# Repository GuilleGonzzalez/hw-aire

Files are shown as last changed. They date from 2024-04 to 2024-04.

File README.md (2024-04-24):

# Aire

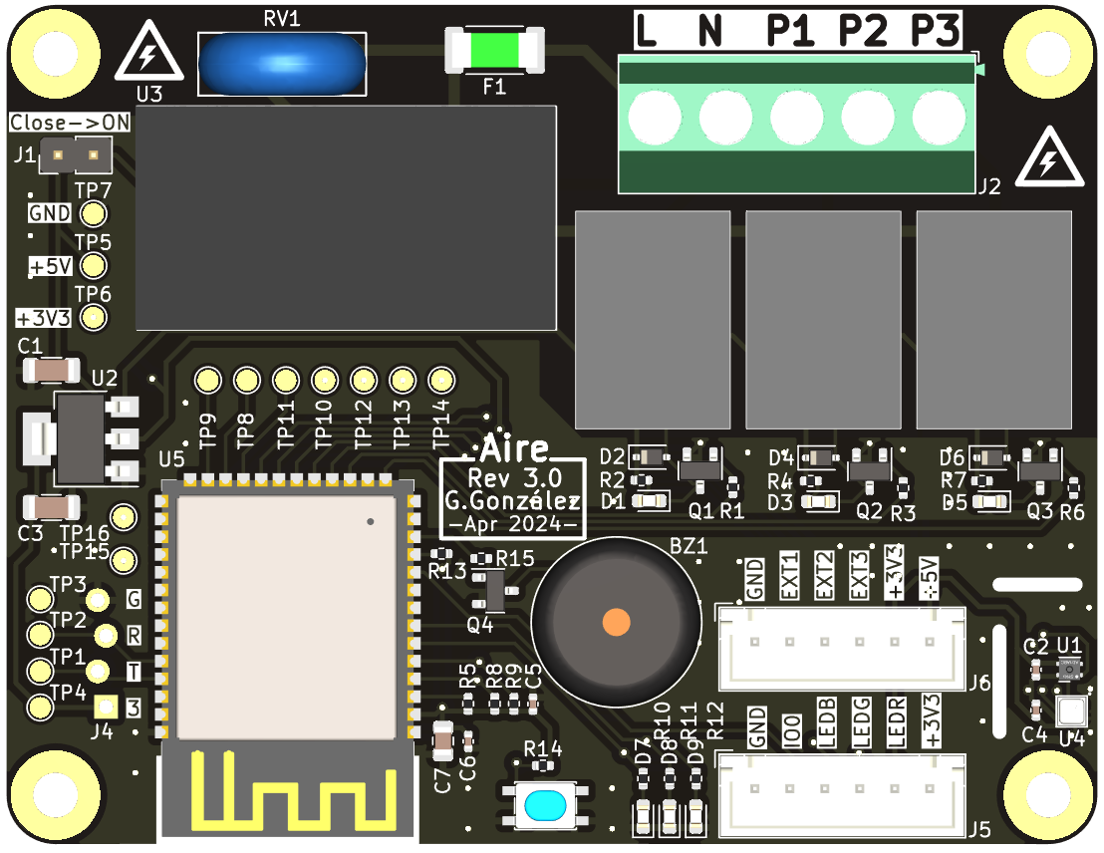
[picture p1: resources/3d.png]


## Description

'Aire' is a PCB designed to control a fan with three relays and automatize it with [Home Assistant](https://www.home-assistant.io/).

Firmware used in this device is [fw-aire](https://github.com/GuilleGonzzalez/fw-aire), a custom made firmware implemented using [Arduino Home Assistant](https://github.com/dawidchyrzynski/arduino-home-assistant/tree/main) Arduino library ([docs](https://dawidchyrzynski.github.io/arduino-home-assistant/)).

## Power supply

The board is powered with a 230VAC power supply.

## Microprocessor

Espressif [ESP32-S2-SOLO](https://www.espressif.com/en/products/modules) module (NRND).

## Environmental sensing

The board has enviromental sensors to measure temperature, humidity and atmospheric pressure:

### Temperature and humidity sensor

* Sensirion [SHT40](https://sensirion.com/products/catalog/SHT40).

### Pressure sensor

* Bosch [BMP581](https://www.bosch-sensortec.com/products/environmental-sensors/pressure-sensors/bmp581/).

## LEDs and buttons

//TODO: review

The device has three LEDs for showing the status to the user.
* A power LED (LED1): shows the status of the fan.
* A general device LED (LED2): shows the status of the general air machine.
* A LED reserved for the future.

The device has a button for flash the firmware in the microcontroller, and is also used for the user.

The board has an external connector available for the three LEDs and the button.

## Pin assignment

| PIN | Func |
| --- | --- |
| TODO | TODO |

## Enclosure (WIP)
* Custom made in [Fusion 360](https://www.autodesk.es/products/fusion-360/overview).

# Changelog
All notable changes to this project will be documented in this section.

The format is based on [Keep a Changelog](https://keepachangelog.com/en/1.0.0/)

## [3.0.0] - 2024-04-24
### Fix
- Change microcontroller for more GPIOs
- Remove IO expander
- SMD LEDs
- Change connectors to JST
- Add external connector
- Envirometal sensors with cutouts for avoid hot
## [2.0.0] - 2023-09-04
### Added
- First stable release in this repository

[Unreleased]: https://github.com/GuilleGonzzalez/hw-aire
[2.0.0]: https://github.com/GuilleGonzzalez/hw-aire/releases/tag/v2.0.0
[3.0.0]: https://github.com/GuilleGonzzalez/hw-aire/releases/tag/v3.0.0

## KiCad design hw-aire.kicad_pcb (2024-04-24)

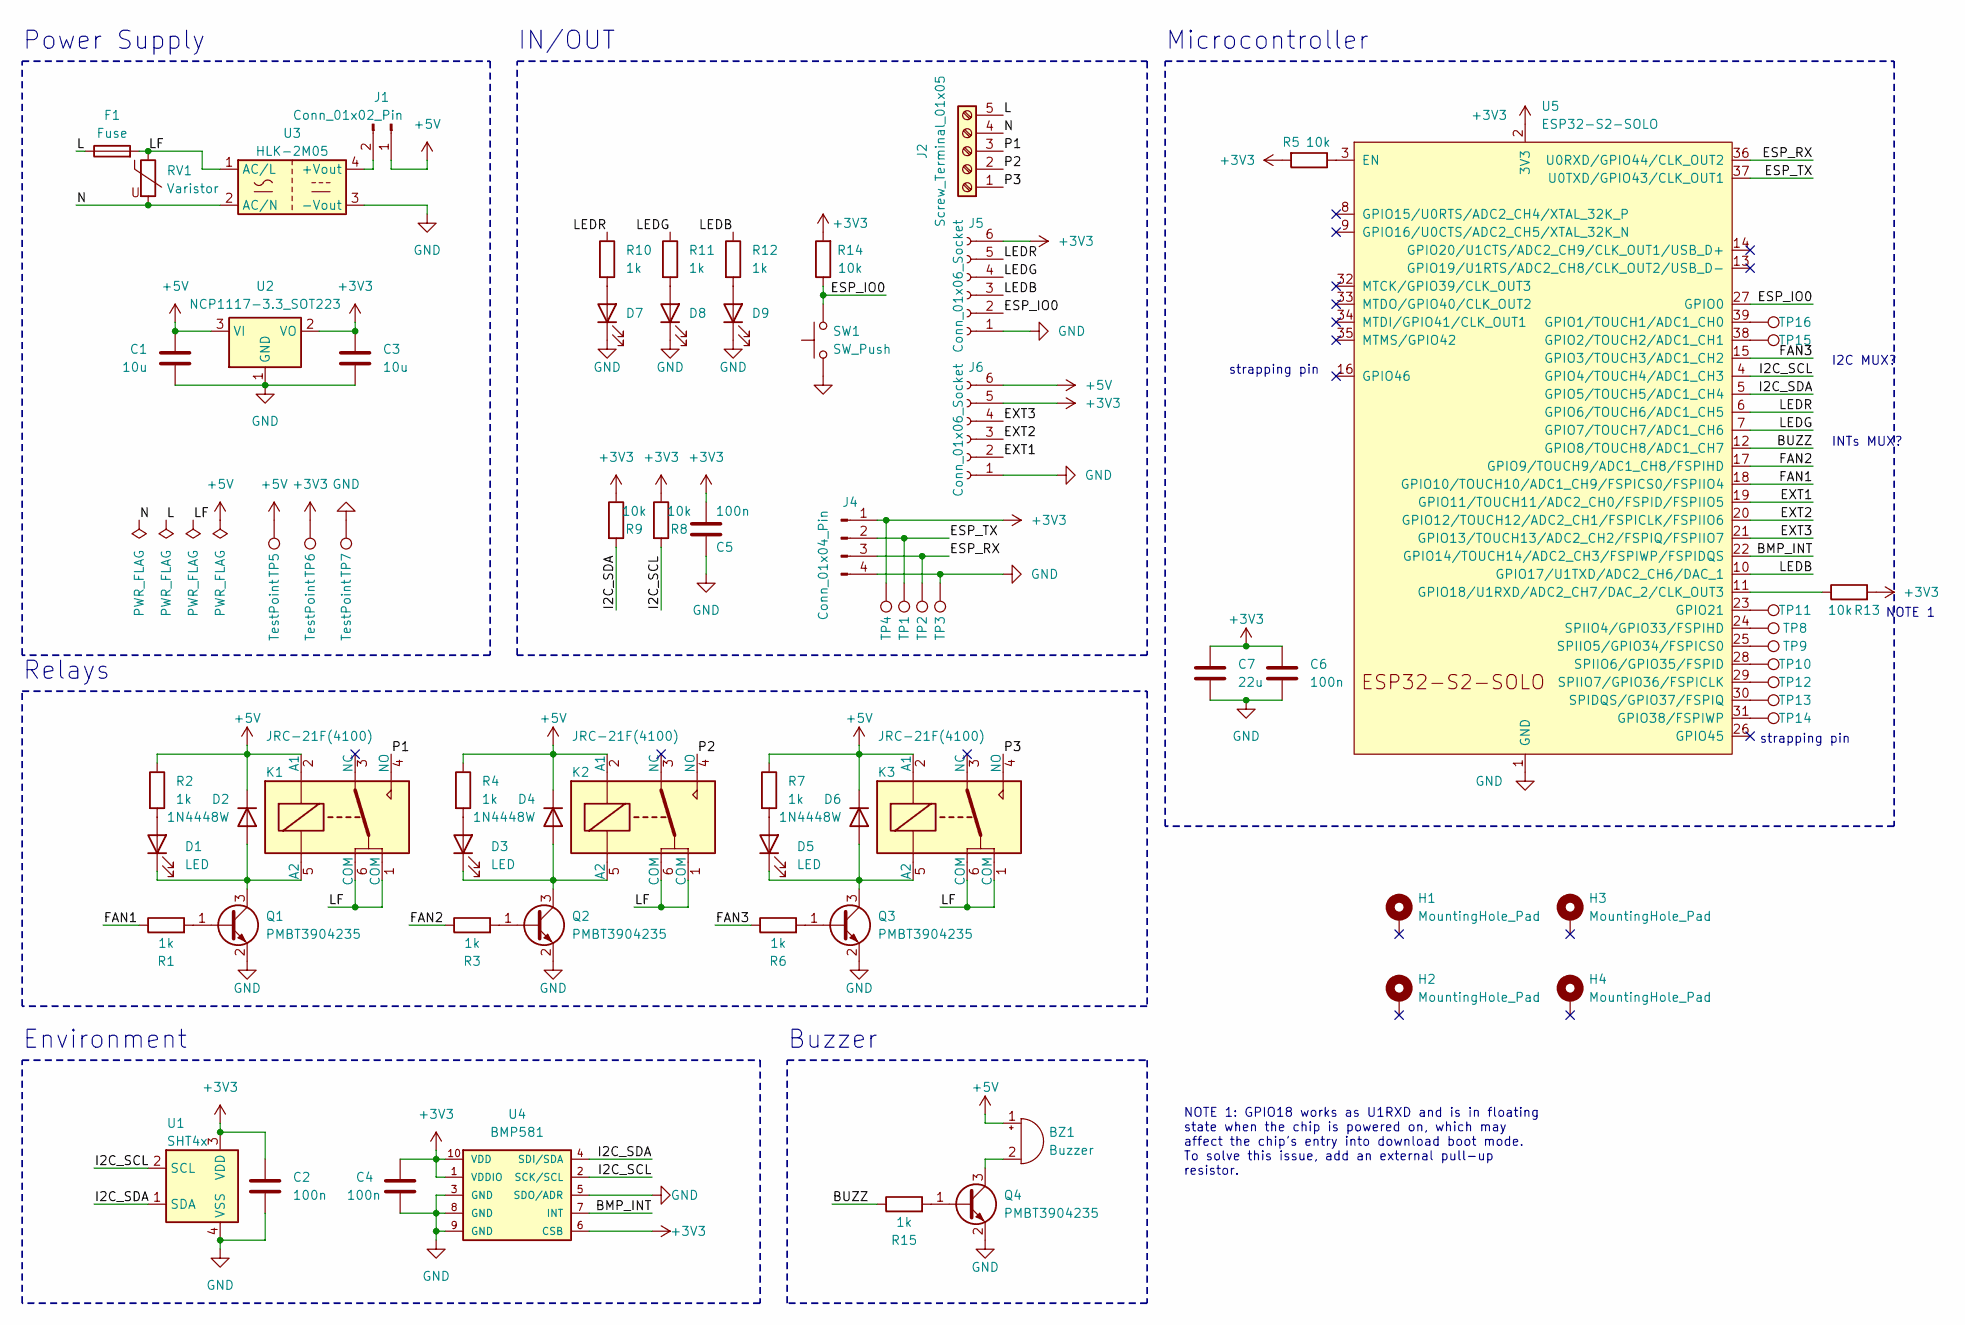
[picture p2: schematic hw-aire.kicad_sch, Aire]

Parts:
BZ1: Buzzer; Buzzer_12x9.5RM7.6
C1, C3: 10u; C_1206_3216Metric
C2, C4, C5, C6: 100n; C_0402_1005Metric
C7: 22u; C_0805_2012Metric
D1, D3, D5, D7, D8, D9: LED; LED_0603_1608Metric
D2, D4, D6: 1N4448W; D_SOD-323
F1: Fuse; Fuse_2512_6332Metric
H1, H2, H3, H4: MountingHole_Pad; MountingHole_3.2mm_M3_Pad_TopBottom
J1: Conn_01x02_Pin; PinHeader_1x02_P2.54mm_Vertical
J2: Screw_Terminal_01x05; TerminalBlock_Phoenix_MKDS-1,5-5-5.08_1x05_P5.08mm_Horizont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
J4: Conn_01x04_Pin; PinHeaderOffset_1x04_P2.54mm_Vertical
J5, J6: Conn_01x06_Socket; JST_XH_B6B-XH-A_1x06_P2.50mm_Vertical
K1, K2, K3: JRC-21F(4100)
Q1, Q2, Q3, Q4: PMBT3904235; SOT-23; Manufacturer_PN PMBT3904,235
R1, R2, R3, R4, R6, R7, R10, R11, R12, R15: 1k; R_0402_1005Metric
R5, R8, R9, R13, R14: 10k; R_0402_1005Metric
RV1: Varistor; RV_Disc_D12mm_W4.5mm_P7.5mm
SW1: SW_Push; SW_SPST_PTS810
TP1, TP2, TP3, TP4, TP5, TP6, TP7, TP8, TP9, TP10, TP11, TP12, TP13, TP14, TP15, TP16: TestPoint; TestPoint_Pad_D1.5mm
U1: SHT4x
U2: NCP1117-3.3_SOT223; SOT-223-3_TabPin2
U3: HLK-2M05
U4: BMP581; Manufacturer PN BMP581
U5: ESP32-S2-SOLO

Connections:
+3V3: C2.1, C3.1, C4.1, C5.1, C6.1, C7.1, J4.1, J5.6, J6.5, R5.2, R8.1, R9.1, R13.2, R14.2, TP4.1, TP6.1, U1.3 (VDD), U2.2 (VO), U4.1 (VDDIO), U4.6 (CSB), U4.10 (VDD), U5.2 (3V3)
+5V: BZ1.1 (-), C1.1, D2.1 (K), D4.1 (K), D6.1 (K), J1.1, J6.6, K1.2 (A1), K2.2 (A1), K3.2 (A1), R2.1, R4.1, R7.1, TP5.1, U2.3 (VI)
/BMP_INT: U4.7 (INT), U5.22 (GPIO14/TOUCH14/ADC2_CH3/FSPIWP/FSPIDQS)
/BUZZ: R15.1, U5.12 (GPIO8/TOUCH8/ADC1_CH7)
/ESP_IO0: J5.2, R14.1, SW1.2, U5.27 (GPIO0)
/ESP_RX: J4.3, TP2.1, U5.36 (U0RXD/GPIO44/CLK_OUT2)
/ESP_TX: J4.2, TP1.1, U5.37 (U0TXD/GPIO43/CLK_OUT1)
/EXT1: J6.2, U5.19 (GPIO11/TOUCH11/ADC2_CH0/FSPID/FSPIIO5)
/EXT2: J6.3, U5.20 (GPIO12/TOUCH12/ADC2_CH1/FSPICLK/FSPIIO6)
/EXT3: J6.4, U5.21 (GPIO13/TOUCH13/ADC2_CH2/FSPIQ/FSPIIO7)
/FAN1: R1.1, U5.18 (GPIO10/TOUCH10/ADC1_CH9/FSPICS0/FSPIIO4)
/FAN2: R3.1, U5.17 (GPIO9/TOUCH9/ADC1_CH8/FSPIHD)
/FAN3: R6.1, U5.15 (GPIO3/TOUCH3/ADC1_CH2)
/I2C_SCL: R8.2, U1.2 (SCL), U4.2 (SCK/SCL), U5.4 (GPIO4/TOUCH4/ADC1_CH3)
/I2C_SDA: R9.2, U1.1 (SDA), U4.4 (SDI/SDA), U5.5 (GPIO5/TOUCH5/ADC1_CH4)
/L: F1.1, J2.5
/LEDB: J5.3, R12.1, U5.10 (GPIO17/U1TXD/ADC2_CH6/DAC_1)
/LEDG: J5.4, R11.1, U5.7 (GPIO7/TOUCH7/ADC1_CH6)
/LEDR: J5.5, R10.1, U5.6 (GPIO6/TOUCH6/ADC1_CH5)
/LF: F1.2, K1.1 (COM), K1.6 (COM), K2.1 (COM), K2.6 (COM), K3.1 (COM), K3.6 (COM), RV1.1, U3.1 (AC/L)
/N: J2.4, RV1.2, U3.2 (AC/N)
/P1: J2.3, K1.4 (NO)
/P2: J2.2, K2.4 (NO)
/P3: J2.1, K3.4 (NO)
GND: C1.2, C2.2, C3.2, C4.2, C5.2, C6.2, C7.2, D7.1 (K), D8.1 (K), D9.1 (K), J4.4, J5.1, J6.1, Q1.2, Q2.2, Q3.2, Q4.2, SW1.1, TP3.1, TP7.1, U1.4 (VSS), U2.1 (GND), U3.3 (-Vout), U4.3 (GND), U4.5 (SDO/ADR), U4.8 (GND), U4.9 (GND), U5.1 (GND), U5.40 (GND), U5.41 (GND)
unnamed: BZ1.2 (+), Q4.3
unnamed: D1.2 (A), R2.2
unnamed: D1.1 (K), D2.2 (A), K1.5 (A2), Q1.3
unnamed: D3.2 (A), R4.2
unnamed: D3.1 (K), D4.2 (A), K2.5 (A2), Q2.3
unnamed: D5.2 (A), R7.2
unnamed: D5.1 (K), D6.2 (A), K3.5 (A2), Q3.3
unnamed: D7.2 (A), R10.2
unnamed: D8.2 (A), R11.2
unnamed: D9.2 (A), R12.2
unnamed: J1.2, U3.4 (+Vout)
unnamed: Q1.1, R1.2
unnamed: Q2.1, R3.2
unnamed: Q3.1, R6.2
unnamed: Q4.1, R15.2
unnamed: R5.1, U5.3 (EN)
unnamed: TP16.1, U5.39 (GPIO1/TOUCH1/ADC1_CH0)
unnamed: TP15.1, U5.38 (GPIO2/TOUCH2/ADC1_CH1)
unnamed: R13.1, U5.11 (GPIO18/U1RXD/ADC2_CH7/DAC_2/CLK_OUT3)
unnamed: TP11.1, U5.23 (GPIO21)
unnamed: TP14.1, U5.31 (GPIO38/FSPIWP)
unnamed: TP13.1, U5.30 (SPIDQS/GPIO37/FSPIQ)
unnamed: TP8.1, U5.24 (SPIIO4/GPIO33/FSPIHD)
unnamed: TP9.1, U5.25 (SPIIO5/GPIO34/FSPICS0)
unnamed: TP10.1, U5.28 (SPIIO6/GPIO35/FSPID)
unnamed: TP12.1, U5.29 (SPIIO7/GPIO36/FSPICLK)

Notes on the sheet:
Buzzer
strapping pin
INTs MUX?
Relays
Power Supply
NOTE 1: GPIO18 works as U1RXD and is in floating state when the chip is powered on, which may affect the chip’s entry into download boot mode. To solve this issue, add an external pull-up resistor.
Environment
NOTE 1
I2C MUX?
Microcontroller
IN/OUT

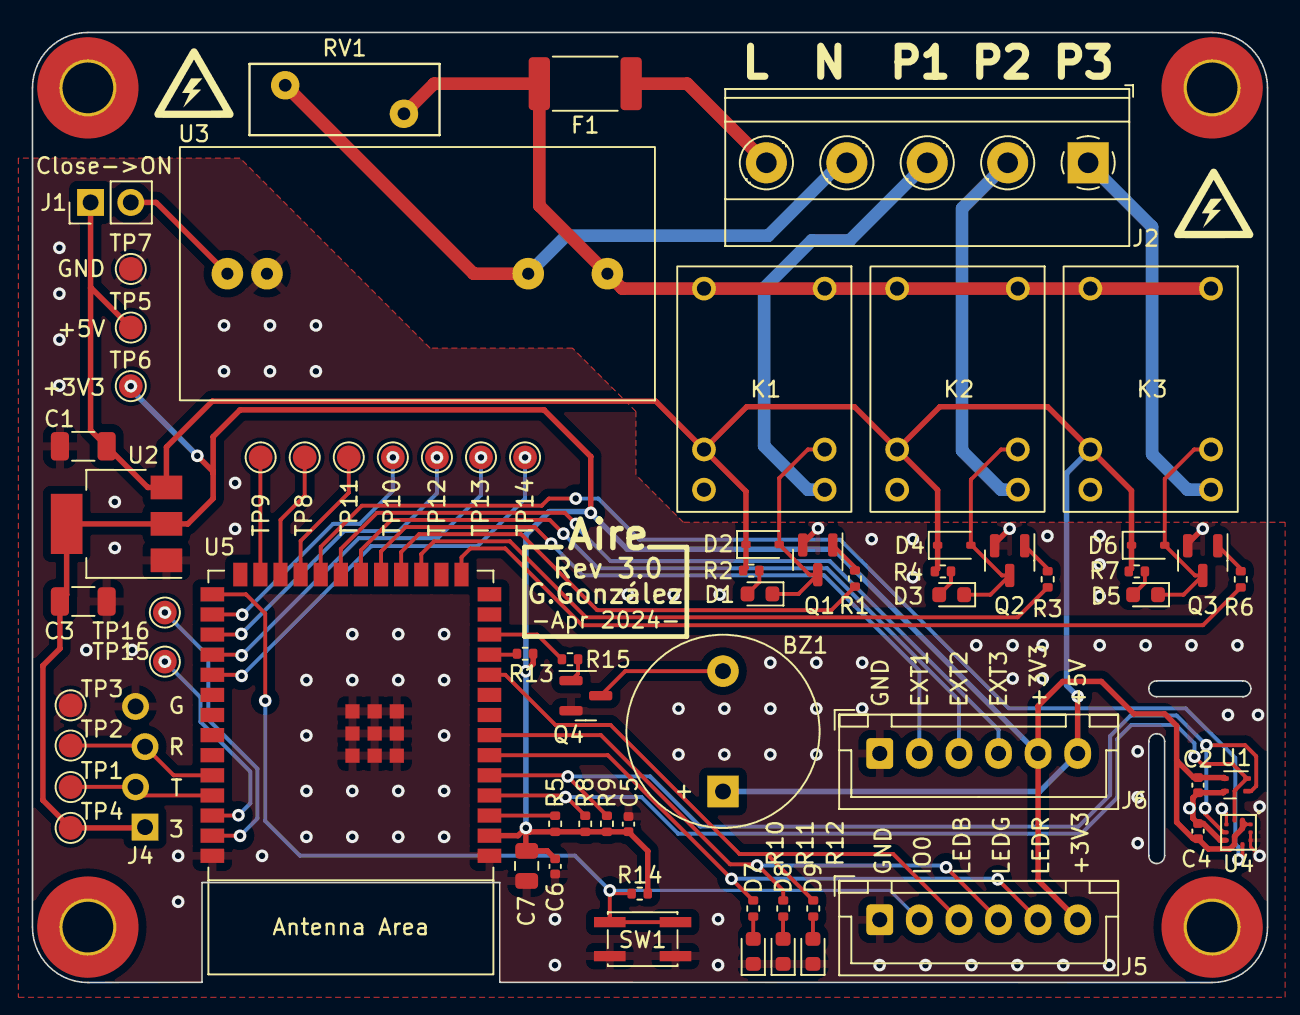
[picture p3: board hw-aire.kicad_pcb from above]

Board: 2 copper layers, 78.0 x 60.0 mm, 72 parts (0 on the bottom side), 51 nets.

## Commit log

2023-08-29 Work in schematic
    [hw-aire.kicad_sch]
2023-08-29 All components linked with fp in schematic
    [hw-aire.kicad_sch]
2023-08-30 Update schematic
    [hw-aire.kicad_sch]
2023-09-02 Sch changes, add net classes and first placement
    [hw-aire.kicad_pcb, hw-aire.kicad_sch]
2023-09-03 Finish routing and serigraphy. Ready to review
    [hw-aire.kicad_pcb, hw-aire.kicad_sch]
2023-09-04 New revision, add IO expander and fix I2C GPIOs
    [hw-aire.kicad_pcb, hw-aire.kicad_sch]
2023-09-04 Revision 2.0
    [hw-aire.kicad_pcb, hw-aire.kicad_sch]
2024-04-17 Add connector label SVG
2024-04-17 Start changing SCH for rev 3.0
    - Change ESP8266 to ESP32-SOLO
    - Change to cold relays
    [hw-aire.kicad_sch]
2024-04-24 Finish PCB rev 3.0
    [hw-aire.kicad_pcb, hw-aire.kicad_sch]
2024-04-24 Revision 3.0
    [hw-aire.kicad_pcb]
